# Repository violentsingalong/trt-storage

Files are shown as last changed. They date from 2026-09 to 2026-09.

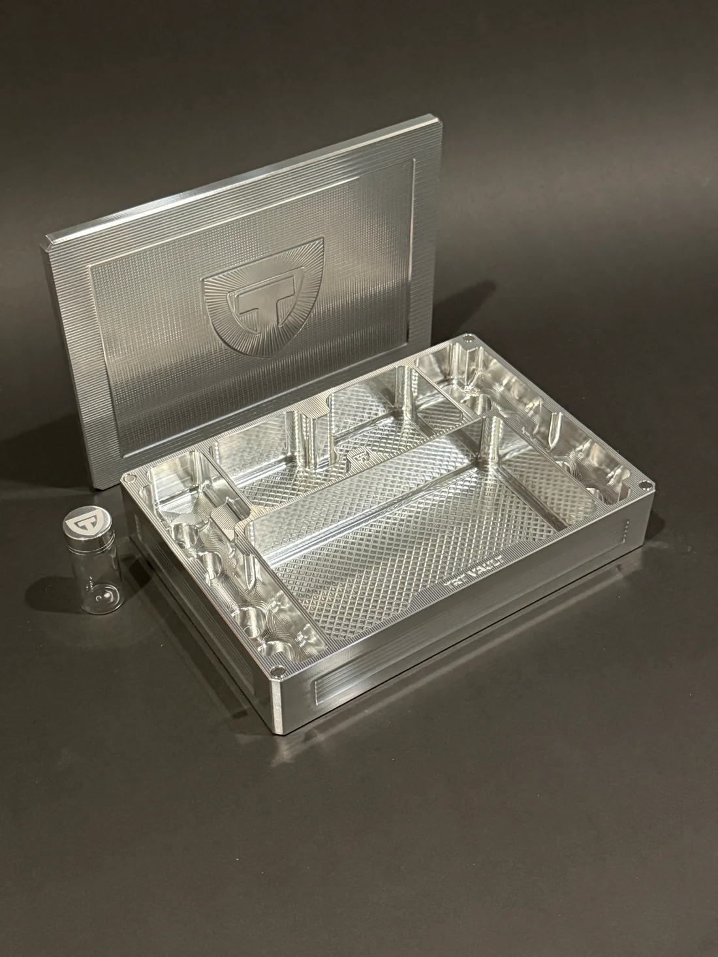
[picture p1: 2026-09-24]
reference/mega_reference.png

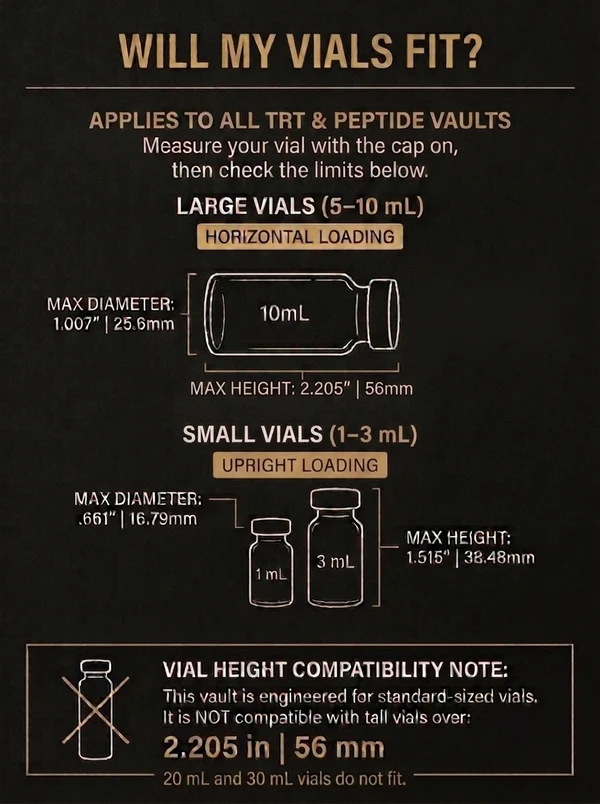
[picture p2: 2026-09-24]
reference/vial_fit_infographic.png

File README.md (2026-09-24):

# Vault Lite

Vault Lite is a parametric, FDM-printable family of magnetic storage cases for medication vials, injection supplies, and related accessories. It is designed for PETG on a Bambu Lab X1 Carbon and uses shared interfaces so matching footprints can stack as modular storage layers.

Commercial products are used only as functional and dimensional references. Vault Lite uses original CAD, visual treatment, and branding.

## Project status

**Current stage: V0.1 calibration complete; stack-interface and Mini prototype are next.**

| Item | Result |
|---|---|
| Small-vial cavity | 17.00 mm tested with current 3 mL vial |
| Horizontal large-vial trough | 26.00 mm selected across several current vials |
| Magnets | Round 6 × 2 mm |
| Magnet pocket | 6.20 mm diameter × 2.20 mm deep; insertion tested |
| Magnet cover | 0.80 mm selected for best surface finish; mating hold test pending |
| CAD toolchain | Dockerized OpenSCAD + ADMesh |
| Printable artifacts | Horizontal vial-fit, vertical vial-well, and magnet-cover coupon STLs exported and validated |

See [the dimension register](docs/dimensions.md) for the distinction between known, inferred, and physically tested values. Packaging envelopes and measurement requirements for prep pads, syringes, and sterile needles are tracked in [the supply-dimensions study](docs/supply-dimensions.md).

## Planned models

### Mini

- Exterior: **152.4 × 127.0 × 44.45 mm**
- Six upright 1–3 mL vial positions
- Secondary supply compartments
- Removable magnetic lid

### Mega

- Exterior: **220 × 160 × 44.45 mm**
- Horizontal 5–10 mL vial storage
- Selectable TRT/supply, expanded vial, and open-cavity layouts

### Cycle Mega

- Exterior: **220 × 160 × 63.5 mm**
- Fourteen upright 5–10 mL vial positions
- Taller variant sharing the Mega X/Y footprint and stack datum
- No fitted 1–3 mL storage

### Future Micro

- Reference footprint: **152.4 × 76.2 mm**
- Recorded for future interface compatibility; not currently part of V1 scope

The 220 × 160 mm footprint is the original Vault Lite Large standard rather than a dimensional copy of the commercial reference. All listed bodies and lids fit within the X1C's 256 × 256 mm build area.

## Modular stack system

Every body is also a storage layer:

- same-footprint layers can stack in any order;
- purpose-built and open-cavity layers share one interface;
- intermediate layers may be lidless;
- only the uppermost layer requires a lid;
- printed registration geometry carries lateral loads;
- corner magnets provide retention rather than alignment;
- lids, parked lids, and stacked bodies use one documented polarity convention.

The registration geometry and polarity map remain under development and will be selected using a two-plate physical coupon.

## Lid appearance

The default lid is monochrome black with a centered, shallow raised user-supplied emblem and a slightly taller perimeter bezel. The bezel protects the emblem and becomes the structural bearing surface when modules stack. The emblem remains a separate CAD region for an optional two-color AMS version.

See [the lid visual-language specification](docs/lid-visual-language.md).

## Repository layout

```text
cad/             Parametric OpenSCAD sources and shared parameters
docs/            Specifications, tested dimensions, and print instructions
exports/stl/     Generated printable meshes
exports/3mf/     Bambu Studio projects after slicer validation
prototypes/      Prototype notes and future iteration artifacts
reference/       Functional and dimensional reference images
```

## Generate and validate models

Requirements: Docker with the Compose plugin.

```sh
make image          # build the local OpenSCAD/ADMesh image
make check          # generate and validate the vial coupon
make check-magnet   # generate and validate the magnet coupon
make check-vertical # generate and validate the Cycle Mega vertical-well coupon
make check-liners    # generate and validate removable vial-liner iterations
make check-liners-v2 # generate and validate the full-depth G1/G3/K1 pass
make check-liner-g3-v3 # generate and validate the single relieved G3 revision
make check-fuzzy     # generate and validate three minimal fuzzy-skin cards
make check-cycle-tray-v0 # generate and validate the shallow Cycle layout study
make check-all      # generate and validate all calibration coupons
```

Generated files are written to `exports/stl/` as the invoking host user.

## Calibration artifacts

### Vial-fit coupon

[Download the current STL](exports/stl/vault-lite-v0.1-vial-coupon.stl)

- Upright wells: 17.0, 17.2, 17.4, and 17.6 mm
- Full-length horizontal troughs: 25.8–26.6 mm
- Current selections: 17.0 mm small-vial cavity and 26.0 mm large-vial trough

### Magnet-cover coupon

[Download the current STL](exports/stl/vault-lite-v0.1-magnet-cover-coupon.stl)

- Magnet: 6 × 2 mm round disc
- Pocket: 6.20 × 2.20 mm
- Tested covers: 0.4, 0.6, and 0.8 mm
- Current selection: 0.8 mm, pending mating-force validation

Follow the [Bambu Studio pause procedure](docs/bambu-studio-magnet-coupon.md). Inserted magnets are encapsulated permanently by this coupon.

### Vertical large-vial coupon

[Download the current STL](exports/stl/vault-lite-v0.1-vertical-vial-coupon.stl)

- Upright wells: 25.4, 25.6, and 25.8 mm
- Well depth: 24 mm with a 1 mm entry chamfer
- Intended to select the Cycle Mega upright-well diameter using the measured vial assortment

### Removable vial-liner iterations

[Download the current STL](exports/stl/vault-lite-v0.1-vial-liner-iterations.stl)

- Three Gereropharm split collars: 24.0, 24.2, and 24.4 mm IDs
- Three KOSA split collars: 22.4, 22.6, and 22.8 mm IDs
- Common provisional outer diameter: 25.4 mm for the selected 25.6 mm well
- Integrated pull tabs and engraved G1–G3/K1–K3 identifiers

### Full-depth vial-liner V2 pass

[Download the current V2 STL](exports/stl/vault-lite-v0.2-vial-liners-g1-g3-k1.stl)

- G1: 24.0 mm ID for Gereropharm
- G3: 24.4 mm ID for Gereropharm
- K1: 22.4 mm ID for KOSA
- Common 25.1 mm OD for 0.5 mm nominal diametral clearance in the 25.6 mm well
- Full 24 mm well depth with the extraction ear above the rim
- Larger labels plus physical notch coding; omitted G2/K2/K3 to minimize material

### Gereropharm G3 printable-wall revision

[Download the current G3 STL](exports/stl/vault-lite-v0.3-vial-liner-g3.stl)

- Single 24.4 mm ID Gereropharm liner
- 25.3 mm outer envelope creates a 0.45 mm radial wall for the 0.4 mm nozzle profile
- Two vertical relief slots and the primary split create flexible petals above a 2 mm connecting band
- Full 24 mm depth with above-rim extraction ear

This STL is retained as an archived test artifact. Physical evaluation established that the measured Gereropharm vial fits the standard 25.6 mm well adequately without a liner. K1 remains the only active liner candidate.

### Cycle tray V0 layout study

[Download the shallow layout-study STL](exports/stl/vault-lite-v0.1-cycle-tray-layout-study.stl)

- Fourteen tested-diameter 25.6 mm upright wells
- Mirrored five-plus-two well banks
- One continuous raised deck with overlapping 34 mm spherical divots and no drop gaps
- Supply cavities share the exterior tray wall instead of duplicating it
- Reserved 8 mm top/bottom walls plus side structure for the planned six-position bar-magnet interface
- Approximately 84.0 × 57.6 mm usable upper packet bay
- Approximately 142.0 × 84.0 mm usable lower packaged-supply bay
- Shallow 26.4 mm review artifact; not yet the final magnetic 63.5 mm body

See [the Cycle tray V0 design note](docs/cycle-tray-v0.md).

## Prototype printing assumptions

- Material: PETG
- Printer: Bambu Lab X1 Carbon
- Body orientation: cavity upward
- Initial production profile: 0.20 mm layer height and four walls
- Exterior finish: normal smooth PETG; fuzzy skin was tested and rejected because it introduced additional artifacts
- Calibration-only vial coupon: 0.24 mm Draft, three walls, 15% gyroid is acceptable
- Supports should be avoided through geometry wherever practical

Final settings will be published only after the body and lid are physically validated.

## Roadmap and issues

Outstanding work is tracked in [GitHub Issues](https://github.com/violentsingalong/trt-storage/issues). The implementation order is:

1. Validate the shared magnetic stack and alignment interface.
2. Build and physically iterate the Mini body and lid.
3. Build and physically iterate the standard Mega layouts.
4. Build the taller Cycle Mega variant.
5. Add matching open-cavity modular layers.
6. Finalize lid artwork, Bambu Studio projects, and release documentation.

The detailed engineering sequence remains in [the project plan](docs/project-plan.md).

## Design constraints

- Keep all geometry parametric and source-controlled.
- Label photograph-derived measurements as inferred.
- Do not reproduce third-party logos, names, or decorative engraving.
- Ensure inserted magnets sit below the active print plane before resuming a paused print.
- Use mechanical indexing so magnets do not carry all lateral shear.
- Validate real storage objects before calling a model production-ready.

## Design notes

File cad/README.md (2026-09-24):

# CAD sources

- `parameters.scad` — single source for shared dimensions and uncertainty status.
- `primitives.scad` — reusable printable geometry.
- `calibration_coupon.scad` — vial-clearance artifact with four upright small-vial wells and five full-length large-vial troughs.
- `magnet_coupon.scad` — three-cover encapsulation test for the measured 6 × 2 mm disc magnets.
- `vertical_vial_coupon.scad` — deep-wall upright-vial fit test for the Cycle Mega family.
- `vial_liner_coupon.scad` — six removable split-collar iterations for narrower large vials.
- `vial_liner_coupon_v2.scad` — full-depth G1/G3/K1 pass with increased well clearance and robust identifiers.
- `vial_liner_g3_v3.scad` — single printable-wall G3 revision with flexible relief slots.
- `fuzzy_skin_coupon.scad` — minimal upright wall card rendered in three labeled variants for per-object Bambu Studio texture settings.
- `cycle_tray_v0.scad` — shallow 14-vial Cycle layout study with upper packet and lower packaged-supply bays; magnet/stack geometry intentionally deferred.

The recommended reproducible workflow uses the included Docker container:

```sh
make image
make check
```

`make check` renders `exports/stl/vault-lite-v0.1-vial-coupon.stl` and then checks the mesh with ADMesh. Files are written as the invoking host user rather than root.

`make check-magnet` renders and checks the 6 × 2 mm magnet-cover coupon. With a 0.20 mm layer height, inspect the slicer preview and pause immediately before the first sealing layer above the nominal 4.60 mm pocket roof. Insert all three magnets with identical polarity and ensure they sit below the active print plane before resuming.

`make check-vertical` renders and checks the 25.4–25.8 mm vertical 5–10 mL vial-well coupon.

`make check-liners` renders and checks the Gereropharm and KOSA split-collar iteration set.

`make check-liners-v2` renders and checks only the full-depth G1, G3, and K1 V2 liners selected after the first physical test.

`make check-liner-g3-v3` renders and checks the single 24.4 mm ID G3 revision after the V2 wall was omitted by the 0.4 mm nozzle slicer profile.

`make check-fuzzy` renders and checks the three 0.05/0.08/0.12 fuzzy-skin cards. The STLs contain labels but no texture; assign the per-object slicer settings in `../docs/bambu-studio-fuzzy-coupon.md`.

`make check-cycle-tray-v0` renders and checks the shallow Cycle tray layout study. This is a plan and ergonomics artifact, not the final 63.5 mm magnetic body.

See `../docs/bambu-studio-magnet-coupon.md` for the Bambu Studio procedure. Save the sliced setup with its verified pause as a Bambu `.3mf` project rather than relying on a fixed layer number in the raw STL.

If OpenSCAD is installed directly on the host, the equivalent export from this directory is:

```sh
openscad -o ../exports/stl/vault-lite-v0.1-vial-coupon.stl calibration_coupon.scad
```

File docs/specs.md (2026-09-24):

# Engineering Specification

## 1. Hard constraints / known inputs

### Printer
Bambu Lab X1 Carbon build envelope: **256 × 256 × 256 mm**

### Mini envelope
- X: 152.40 mm
- Y: 127.00 mm
- Z: 44.45 mm

### Vault Lite Large envelope
- X: 220.00 mm
- Y: 160.00 mm
- Z: 44.45 mm

The commercial Mega reference is 215.90 × 152.40 mm, but Vault Lite is not constrained to that footprint. The selected 220 × 160 mm metric footprint provides safe bar-magnet landing zones and is shared by standard Large, Cycle, and open-layer variants.

### Reference ecosystem Micro envelope
- X: 152.40 mm
- Y: 76.20 mm
- Z: 44.45 mm
- recorded for future interface compatibility; not a V1 deliverable yet

### Vial compatibility
Large vials (5–10 mL), horizontal:
- max diameter: **25.60 mm**
- max overall length: **56.00 mm**

Small vials (1–3 mL), upright:
- max diameter: **16.79 mm**
- max height: **38.48 mm**

These are vial envelopes, not cavity dimensions.

## 2. Reference observations

### Mini
The supplied top view shows:
- four corner magnets;
- thin perimeter rail;
- three principal storage zones;
- upper-left 3 × 2 small-vial pattern;
- upper-right general-purpose compartment with finger-access reliefs;
- large lower supply compartment with central finger relief;
- shallow textured floors.

The vial geometry appears to support overlapping horizontal large-vial use. Exact interior dimensions are unknown and photo-derived estimates must be tagged `INFERRED`.

### Mega
The supplied oblique image shows:
- four corner magnets;
- same general magnetic-lid language;
- multiple long supply channels/compartments;
- repeated vial-access scallops along one side;
- large central/lower storage area;
- monolithic machined body.

The added near-top-down loaded view also shows:
- mirrored left/right horizontal-vial banks;
- two upper alcohol-swab bays;
- one broad lower syringe/supply bay;
- finger-access notches at the central bays.

### Mega main-box layout options

Keep the Mega source capable of generating more than one interior layout while preserving the same exterior, lid, magnet, and stacking interface:

1. **TRT + supplies:** mirrored horizontal large-vial banks, upper swab compartments, and a broad syringe/supply bay.
2. **Vials + pill containers:** increase the count of universal horizontal large-vial channels; each channel retains the 25.60 × 56.00 mm compatibility envelope and therefore also accepts the user's candidate pill containers at approximately 21.0 × 51.5 mm.
3. **Open main box:** one large cavity for unconstrained storage, using the same modular-layer interface.
4. **Cycle Large family (separate height variant):** mirrored upright 5–10 mL vial banks along the left and right edges, one centered upper swab/packet bay with bilateral finger access, and one large centered lower syringe/supply bay. This is not a 44.45 mm Large interior option; it requires a taller body while retaining the 220 × 160 mm X/Y footprint and stack-interface datum.

The pill container is a fit-use case, not a controlling design dimension. Do not narrow universal channels around that specific product.

The Cycle Mega is deliberately for upright 5–10 mL vials and does **not** provide fitted 1–3 mL positions; small vials would sit loose and may rattle. Preserve adequate finger access between adjacent large-vial positions and at the swab bay.

Use **25.60 mm** as the uniform Cycle Mega upright-well diameter. The 25.40 mm coupon well fit the 25.04 mm Pharmacom vial closely, but 25.60 mm was selected to tolerate label seams, glass variation, and other minor imperfections without compromising insertion.

Support the narrower KOSA vial with an optional removable reducer liner rather than multiple permanent well sizes. The measured Gereropharm vial is accepted directly in the 25.60 mm well without a liner. Preferred remaining liner concept:

- full-well-depth split collar or compliant insert;
- smooth PETG contact surfaces, with TPU retained as an optional high-grip variant;
- common outer geometry fitting the 25.60 mm well;
- K1/22.40 mm candidate inner geometry for the measured KOSA vial;
- three shallow internal centering ribs where practical to reduce material and label drag;
- positive finger-removal feature entirely above the rim so the insert bottoms before the feature carries insertion load;
- enough compliance to accommodate label seams and vial ovality;
- no insert required for the Pharmacom or Gereropharm vial.

Validate liner outer clearance, retention, vial release, and whether the insert lifts out with the vial using a dedicated small coupon before integrating it into the Cycle Mega release.

Use **63.50 mm (2.5 inches)** as the Cycle Mega reference exterior height, based on the written product specification. An image on the same page lists 2.25 inches; treat that graphic as inconsistent or outdated rather than allowing it to override the page's explicit Dimensions & Build section. The printable design must still verify that its floor, lid, and safe Z clearances fit the 56 mm capped-vial envelope.

Perspective correction may estimate proportions, but resulting measurements remain `INFERRED`.

## 3. Minimum parameter set

```text
mini_x = 152.40
mini_y = 127.00
mega_x = 220.00
mega_y = 160.00
case_z = 44.45

small_vial_max_d = 16.79
small_vial_max_h = 38.48
large_vial_max_d = 25.60
large_vial_max_l = 56.00

small_vial_clearance = TBD_FROM_COUPON
large_vial_clearance = TBD_FROM_COUPON

magnet_x_or_d = REQUIRED_USER_INPUT
magnet_y = REQUIRED_USER_INPUT_IF_RECTANGULAR
magnet_z = REQUIRED_USER_INPUT
magnet_cover = TBD_FROM_COUPON

lid_gap_xy = PARAMETRIC
alignment_clearance = PARAMETRIC
outer_corner_radius = PARAMETRIC
min_wall = PARAMETRIC
floor_thickness = PARAMETRIC
lid_thickness = PARAMETRIC
```

Measured magnet input: round disc, **6.00 mm diameter × 2.00 mm thick**. The first coupon uses a 6.20 mm diameter × 2.20 mm deep pocket, which accepted all three test magnets. Of the tested 0.4, 0.6, and 0.8 mm covers, **0.8 mm produced the best visual surface with only slight magnet witness**. Treat 0.8 mm as preferred pending body-to-lid holding-force testing.

Never silently invent magnet dimensions.

## 4. FDM adaptation rules

The reference is CNC aluminum and cannot simply be copied dimension-for-dimension.

Starting guidelines:
- structural dividers: ~2.0–2.5 mm minimum unless testing supports thinner;
- printable fillets/chamfers;
- avoid deep unsupported horizontal ceilings;
- magnet encapsulation roof must bridge reliably;
- clearance around real vials rather than nominal zero-clearance fits;
- finger reliefs for tightly packed supplies.

## 5. Lid

Desired:
- removable slab-style lid;
- four-corner magnetic retention;
- tongue/rebate, bosses, or equivalent geometry controlling X/Y movement;
- easy finger access;
- visually flush/near-flush perimeter;
- optional magnetic parking beneath body.

Do not rely on magnets alone for lateral registration.

## 5A. Stack interface

Every case body is also a modular storage layer. The interface must support:
- stacking only with an identical X/Y footprint;
- a lidded top layer or a lidless intermediate layer;
- repeatable X/Y registration using printable mechanical geometry;
- four-corner magnetic retention using one documented polarity map;
- body-to-body stacking and lid parking without polarity conflicts;
- separation by hand without tools or excessive prying force;
- a flat, printable body underside without support-heavy recesses.

Interface geometry is `TBD_FROM_COUPON`. Do not finalize corner offsets, magnet pockets, registration depth, or polarity until actual magnets are measured and a two-plate stack coupon is tested.

Open-cavity layers should target the published reference cavity depth of approximately 34.0 mm only after floor, interface, and lid geometry are reconciled within the 44.45 mm exterior height.

## 6. Pause-and-insert magnet process

1. Print until magnet pocket is open.
2. Pause before sealing layers.
3. Insert magnets using a polarity map/jig.
4. Confirm magnets are below the current print plane.
5. Resume and bridge/seal pockets.

## 7. Calibration coupon

### Small vial wells
17.0 / 17.2 / 17.4 / 17.6 mm IDs.

### Large vial troughs
25.8 / 26.0 / 26.2 / 26.4 / 26.6 mm effective diameters.

Each trough must provide at least 60 mm of usable axial length so the known 56 mm maximum large vial can be seated completely rather than testing diameter at only one short contact section.

Physical coupon result: use **26.00 mm effective diameter** for the current horizontal large-vial configuration. Multiple differently sized user vials fit comfortably, and the semicircular exposure provides useful finger access. This selection is tested for the user's assortment and supplies 0.40 mm nominal diametral clearance over the published 25.60 mm envelope.

### Magnet covers
After magnet dimensions are known: 0.4 / 0.6 / 0.8 mm.

Record insertion feel, rattle, grip strength, removal effort, and print artifacts.

## 8. Open measurements

Required before final magnet design:
- magnet shape;
- diameter OR length × width;
- thickness;
- quantity available.

Useful validation:
- actual 10 mL vial dimensions;
- actual peptide vial dimensions;
- syringe dimensions;
- alcohol-swab packet dimensions;
- pill vial/accessory dimensions.

The manufacturer maximum vial envelopes remain compatibility targets even if current supplies are smaller.

## 9. Originality

Use commercial references for functional inspiration and dimensional interoperability. Do not reproduce the TRT Vault name, shield/T logo, decorative engraving, or branding. Develop original surface treatment and labeling.

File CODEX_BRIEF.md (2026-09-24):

# Codex Project Brief

Implement a parametric FDM storage-case project called **Vault Lite**.

Read:
1. `README.md`
2. `docs/specs.md`
3. `docs/project-plan.md`
4. all files in `reference/`

Rules:
- Separate KNOWN, INFERRED, and TESTED dimensions.
- Never invent unknown magnet dimensions.
- Keep geometry parametric and source-controlled.
- Prefer OpenSCAD initially unless another scriptable CAD workflow clearly improves the result.
- Design for PETG on a Bambu Lab X1 Carbon.
- First printable artifact is a calibration coupon, not a full case.
- Do not copy third-party logos or branding.
- Commercial products are functional/layout references, not a request for a trademark-identical replica.
- Mini and Mega should share reusable CAD primitives and visual language.
- Document uncertainty for every photo-derived measurement.

Start by:
1. creating the CAD skeleton and central parameter file;
2. documenting KNOWN / INFERRED / TBD dimensions;
3. analyzing the Mini reference;
4. producing a first calibration-coupon source file that can be completed once magnet dimensions are supplied.

Do not proceed to a production-ready case while required physical dimensions remain unresolved.

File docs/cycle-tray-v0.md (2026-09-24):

# Cycle tray V0 layout study

This shallow study establishes the interior plan before the ordered bar magnets and shared stack interface are physically validated. It is not the final 63.5 mm body.

## Plan

- Footprint: **220 × 160 mm**, the selected Vault Lite Large standard. The former 215.9 × 152.4 mm footprint remains a commercial reference only.
- Fourteen 25.6 mm upright vial wells cut into one continuous monolithic deck.
- Left and right banks each contain five wells in the outer column plus two wells at the packet end of the inner column.
- Retaining-well height: 24 mm above a 2.4 mm floor.
- Each opening has a 34 mm shallow spherical divot. Adjacent divots overlap intentionally to create a continuous machined appearance and improve vial access.
- The closed deck prevents small supplies and debris from falling between vial cylinders, supply bins, and the outer wall; the slicer may use normal internal infill rather than printing the deck solid.
- The upper and lower supply cavities use the exterior tray wall directly at the top and bottom edges. There is no redundant parallel compartment wall.
- The two supply cavities share one 2.4 mm internal divider.
- Reserved top and bottom long-edge magnet walls: 8.0 mm wide, reclaimed from the wipe and syringe cavities; exact pockets remain pending physical tests.
- Upper packet-bay usable opening: approximately 84.0 × 57.6 mm.
- Lower packaged-supply-bay usable opening: approximately 142.0 × 84.0 mm.
- Upper bay has bilateral finger-access scallops.
- The measured 136 mm sterile 1 mL syringe package fits lengthwise in the lower bay with approximately 6.0 mm total nominal allowance.
- The common approximately 50 × 50 mm alcohol-prep packet envelope fits the upper bay.

## Deferred geometry

- 20 × 5 × 2 mm bar-magnet pockets and polarity map;
- exposed versus 0.8 mm-covered magnetic faces;
- final lid seat and stack registration;
- final full-height perimeter and exact 56 mm lid clearance;
- corner landing pads shared by lid and body-to-body stacking.

The source can preview a provisional full-height perimeter using `LAYOUT_STUDY=false`, but that mode is intentionally not treated as a production body until the magnetic interface is selected.

The first and last vial rows leave 9.2 mm between the 25.6 mm vial envelope and the top/bottom exterior edges. This provides 1.2 mm of nominal PETG between the vial envelope and each reserved 8 mm long-edge wall. The outer vial columns were also shifted inward to reserve separate left/right magnet structure. Together these zones can support a six-position layout—two pockets per short edge and one centered pocket per long edge—without expanding the footprint; exact pockets remain pending physical magnet tests.

## Review before a full body print

- Confirm the five-plus-two well pattern matches the intended Cycle layout.
- Review the overlapping 34 mm spherical divots and confirm the depth/visual rhythm before a full-height print.
- Confirm a single upper packet bay is preferred over a divider.
- Place representative packaged syringes/needles on the plan or in a shallow print and assess retrieval.
- Confirm the lower bay should remain one bulk bin rather than receive a removable divider.

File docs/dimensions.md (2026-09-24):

# Dimension register

All dimensions are millimetres. `INFERRED` values must not be treated as production measurements, and `TESTED` values must name the print/material used.

| Feature | Value | Status | Source / note |
|---|---:|---|---|
| Micro exterior X × Y × Z | 152.40 × 76.20 × 44.45 | KNOWN_REFERENCE | Published 6 × 3 × 1.75 in footprint; future scope |
| Mini exterior X × Y × Z | 152.40 × 127.00 × 44.45 | KNOWN | Supplied handoff |
| Commercial Mega reference X × Y × Z | 215.90 × 152.40 × 44.45 | KNOWN_REFERENCE | Functional reference only; no longer the controlling printable footprint |
| Vault Lite Large exterior X × Y × Z | 220.00 × 160.00 × 44.45 | SELECTED_DESIGN | Shared metric footprint for Large, Cycle, and open-layer modules |
| Small vial maximum Ø × H | 16.79 × 38.48 | KNOWN | Supplied compatibility graphic |
| Large vial maximum Ø × L | 25.60 × 56.00 | KNOWN | Supplied compatibility graphic |
| User's tallest current large vial, cap included | 55.00 long | KNOWN_USER_MEASURED | Physical vial measurement supplied by user |
| Gereropharm vial: body Ø / cap Ø / overall H / straight body H | 23.87 / 22.20 / 54.40 / 40.50 | KNOWN_USER_MEASURED | Body diameter includes label |
| Pharmacom vial: body Ø / cap Ø / overall H / straight body H | 25.04 / 21.76 / 44.89 / 31.90 | KNOWN_USER_MEASURED | Body diameter includes label; preferred brand and largest measured body |
| KOSA vial: body Ø / cap Ø / overall H / straight body H | 22.21 / 22.04 / 54.01 / 42.05 | KNOWN_USER_MEASURED | Body diameter includes label |
| Candidate pill container Ø × capped length | ≈21.0 × 51.5 | REFERENCE_ONLY | Product listing; fits universal large-vial channel but does not control geometry |
| Small-vial pocket pattern | 3 × 2 | INFERRED | Mini reference photograph |
| Corner magnet count | 4 per mating part | INFERRED | Mini and Mega photographs |
| Mega major storage arrangement | 2 side vial banks + 2 upper bays + 1 lower bay | INFERRED | Near-top-down loaded Mega photograph |
| Cycle Mega arrangement | 14 upright 5–10 mL positions + upper packet bay + lower supply bay | KNOWN_REFERENCE | Separate taller variant; excludes fitted 1–3 mL storage |
| Commercial Cycle Mega reference X × Y × Z | 215.90 × 152.40 × 63.50 | KNOWN_REFERENCE | Written product specification: 8.5 × 6 × 2.5 in; same-page comparison graphic inconsistently says 2.25 in |
| Vault Lite Cycle exterior X × Y × Z | 220.00 × 160.00 × 63.50 | SELECTED_DESIGN | Uses the shared Vault Lite Large footprint; height remains provisional pending lid/interface reconciliation |
| Vault Lite Large top/bottom magnet walls | 8.00 wide | PROVISIONAL_LAYOUT | Highlighted long-edge walls; reclaimed from wipe/syringe cavity depth for 20 × 5 mm bar-pocket study |
| Cycle Mega provisional clear internal height | 56.00 | PROVISIONAL | Controlled by 54.40 mm tallest measured standing vial; provides 1.60 mm nominal top clearance |
| Magnet shape and size | round Ø6.00 × 2.00 | KNOWN_USER_MEASURED | User-supplied magnet dimensions |
| Magnet pocket Ø × depth | 6.20 × 2.20 | TESTED_INSERTION | All three 6 × 2 mm magnets seated successfully in coupon; retention/production repeatability pending |
| Magnet encapsulation cover | 0.80 | TESTED_VISUAL | Least magnet witness/print-through of 0.4, 0.6, 0.8 mm coupon; holding force still pending |
| Small-vial cavity / clearance | 17.00 / 0.21 diametral | TESTED_CURRENT_VIAL | User reports comfortable fit with current 3 mL vial; nominal 16.79 mm maximum not physically tested |
| Large-vial trough / clearance | 26.00 / 0.40 diametral | TESTED_CURRENT_VIALS | User tested several differently sized capped vials; 26.0 mm reported as the sweet spot |
| Vertical large-vial well | 25.60 | TESTED_CURRENT_VIALS | Selected over snug 25.4 mm to tolerate vial imperfections and preserve smooth insertion |
| Reducer-liner V1 outer Ø / clearance | 25.40 / 0.20 diametral | TESTED_TOO_TIGHT | Gereropharm collars fit vial outside well but required excessive force in 25.60 mm well |
| Reducer-liner V2 candidate outer Ø / clearance | 25.10 / 0.50 diametral | PROVISIONAL_NEXT_COUPON | Increase reliable insertion clearance while retaining centering |
| Gereropharm liner G1, 24.0 ID | 0.13 nominal vial clearance | TESTED_TOO_TIGHT_IN_WELL | Assembly can be inserted together, but vial cannot be reinserted after removal |
| Gereropharm liner G3, 24.4 ID | 0.53 nominal vial clearance | SLICER_REJECTED_V2_WALL | 25.10 OD left 0.35 mm radial wall; 0.4 mm nozzle profile omitted collar toolpaths |
| Gereropharm in 25.6 well | 1.73 diametral / 0.865 radial clearance | ACCEPTED_NO_LINER | User accepts direct fit; dedicated Gereropharm liner development closed as unnecessary |
| Gereropharm liner G3 V3, 24.4 ID / 25.3 OD | 0.45 radial wall / 0.30 well clearance | ARCHIVED_TEST_ARTIFACT | Superseded by accepted direct vial fit; retained only as development history |
| KOSA liner IDs | 22.4 / 22.6 / 22.8 | PARTIAL_TEST | Suspected K1/22.4 fit 22.21 mm vial; poor label legibility prevents definitive identification |
| Reducer-liner V2 height | 24.00 | PROVISIONAL_NEXT_COUPON | Full test-well depth; extraction feature must sit entirely above rim |
| Common alcohol-prep pouch | ≈50 × 50 | REFERENCE_ONLY | Published examples; actual sealed packets and stack height still required |
| Provisional alcohol-prep bay usable X × Y | 54 × 55 | INFERRED | Intended for common 50 × 50 mm packets with finger relief |
| Provisional loose-syringe bay usable X × Y | 160 × 90 | INFERRED | Photo-derived Mega/Cycle study; final size depends on stored 1 mL and 3 mL assemblies |
| Sterile 1 mL syringe package length | 136.0 | KNOWN_USER_MEASURED | Longer than user's packaged 3 mL syringe; current syringe-package length controller |
| Individually wrapped 1-inch Luer-lock needle package length | ≈91.0 | KNOWN_USER_MEASURED | Shared bulk bin; individual package width does not control geometry |
| Lid XY clearance | 0.30 provisional | INFERRED | Must be calibrated with alignment test |
| Structural wall | 2.40 provisional | INFERRED | PETG starting rule, not yet tested |
| Exterior PETG surface finish | Normal smooth / fuzzy skin disabled | TESTED_SELECTION | 0.12 mm thickness at 0.40 mm distance was best fuzzy sample, but showed more artifacts than normal finish |
| Reference open-cavity depth | ≈34.0 | KNOWN_REFERENCE | Published 1.34 in; reconcile printable floor/interface |
| Stack registration geometry | — | TBD | Select using two-plate PETG coupon |
| Stack magnet polarity map | — | TBD | Requires actual magnets and physical polarity jig |

## Reference-analysis limits

The Mini image is close to top-down but still contains lens/perspective error and no scale object on the same plane. The exterior aspect ratio can constrain a later rectification, but internal dimensions remain estimates. The original Mega image is strongly oblique; the added loaded top view is better for layout interpretation, but supplies obscure compartment edges and it is still unsuitable for precise measurements. For the first prototype, storage-object measurements should control geometry rather than pixel-derived pocket sizes.

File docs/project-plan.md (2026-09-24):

# Project Plan

## Phase 0 — Repository bootstrap
- Create parametric CAD source structure.
- Centralize parameters.
- Preserve reference images.
- Maintain a KNOWN / INFERRED / TESTED dimension log.
- Establish reproducible export commands.
- Define one versioned lid/body/stack interface shared by all footprints.

**Exit:** repository can generate a simple STL reproducibly.

## Phase 1 — Reference analysis

### Mini
- Rectify near-top-down image using known 152.4 × 127.0 mm envelope.
- Estimate compartment boundaries, vial-center pitch, corner magnet positions, wall widths, radii, and finger reliefs.
- Cross-check scale against known vial envelope.

### Mega
- Perspective-correct the commercial reference using its known 215.9 × 152.4 mm envelope; do not treat that as the controlling Vault Lite footprint.
- Estimate major compartment boundaries and repeated geometry.
- Explicitly label confidence/uncertainty.

**Exit:** dimension sketches/tables with confidence labels.

## Phase 2 — Calibration coupon
- Generate vial-fit ladder.
- Add magnet-cover samples after magnet dimensions arrive.
- Add small alignment-lip test if useful.
- Add two mating stack plates to test registration clearance, separation feel, and magnet polarity.
- Export STL.
- User prints in PETG on X1C and reports fit.

**Exit:** tested vial clearances and magnet cover thickness.

## Phase 3 — Mini prototype
- Model Mini body and lid.
- Use calibrated vial clearances.
- Six upright small-vial positions.
- Preserve compact three-zone organization inspired by reference.
- Finger reliefs.
- Four corner magnet pockets.
- Stack-compatible underside using the shared interface.
- Document slicer pause layer.

Evaluate vial fit, lid registration, magnet force, usability, warping, and surface quality.

**Exit:** Mini issue list or accepted geometry.

## Phase 4 — Mini refinement
- Correct from physical feedback.
- Improve chamfers/radii/surface treatment.
- Add restrained original labeling only after geometry is stable.

**Exit:** Mini release candidate.

## Phase 5 — Mega prototype
- Reuse shared case/lid primitives.
- Target the selected 220 × 160 × 44.45 mm Vault Lite Large envelope.
- Prioritize horizontal 5–10 mL vial storage and larger supply storage.
- Make the 44.45 mm interior layout selectable: TRT/supplies, expanded universal vial-and-pill-container channels, or open main box.
- Treat Cycle Mega as a separate taller body sharing the Mega X/Y footprint and stack interface; it stores 5–10 mL vials upright and intentionally omits fitted 1–3 mL storage.
- Use uniform 25.60 mm upright wells and provide optional removable reducer liners for narrower 5–10 mL vial bodies.
- Use same magnetic/alignment system where practical.
- Preserve the same stack-interface version and polarity convention as Mini.
- Body and lid each remain single-piece X1C prints.

**Exit:** Mega V0 STL.

## Phase 6 — Mega physical iteration
Repeat physical review loop.

**Exit:** Mega release candidate.

## Phase 7 — V1 release
- Normalize visual language across both sizes.
- Finalize documentation.
- Add print/assembly guide.
- Include at least one lidless open-cavity storage layer per released footprint.
- Export STLs.
- Add 3MF only after Bambu Studio settings are validated.

## Priority order
1. Correct fit
2. Reliable printing
3. Safe/repeatable magnet insertion
4. Lid feel/registration
5. Storage ergonomics
6. Appearance
7. Decoration

Do not spend substantial effort reproducing CNC floor texture during early prototypes.

## Decisions already made
- Bambu Lab X1 Carbon.
- Ordinary PETG for prototypes.
- Mini primarily for peptide/small-vial storage.
- Mega primarily for TRT/supply storage.
- Monolithic bodies for V1.
- Magnetic removable lids are core.
- Pause-and-insert captive magnets preferred.
- Four corner magnets initially.
- Same-footprint bodies form modular stacks; only the top layer requires a lid.
- Original branding only.

## Questions Codex should surface instead of guessing
- Exact magnet dimensions.
- Preferred lid thickness after magnet geometry is known.
- Supply dimensions when they materially affect layout.
- Whether underside lid parking is worth added complexity after V0.

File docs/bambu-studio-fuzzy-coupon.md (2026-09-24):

# Bambu Studio: fuzzy-skin coupon

The three STL cards are geometrically identical except for their recessed foot labels. Fuzzy skin is generated by Bambu Studio and is not stored in an STL.

## Import and arrange

1. Import all three fuzzy-skin coupon STLs as separate objects.
2. Keep them upright as modeled, with several millimetres between cards.
3. Use the intended black PETG and the same wall speeds planned for the case.
4. If bed adhesion is questionable, add a small brim to all three objects rather than changing their geometry.

## Per-object settings

Use **0.40 mm point distance** for all three objects and assign the labeled fuzzy-skin thickness to each card:

| Card label | Fuzzy-skin thickness | Point distance |
|---:|---:|---:|
| 0.05 | 0.05 mm | 0.40 mm |
| 0.08 | 0.08 mm | 0.40 mm |
| 0.12 | 0.12 mm | 0.40 mm |

Apply fuzzy skin to the exterior contour. Confirm in Preview that each broad vertical face receives texture. The feet and labels are not evaluation surfaces.

## Evaluation

Compare the cards under both direct and grazing light for:

- layer-line masking;
- visual uniformity;
- tactile roughness and grip;
- tendency to collect lint;
- corner definition;
- preference at normal viewing distance.

Record the selected thickness together with filament, nozzle, layer height, wall speed, and Bambu Studio profile. Do not apply fuzzy skin to lid fits, stack registration, bezel bearing surfaces, magnet interfaces, or interior storage surfaces.

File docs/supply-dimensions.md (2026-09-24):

# Supply dimension envelopes

This document separates published product dimensions, photo-derived layout estimates, and measurements still required from the user's actual supplies. All dimensions are millimetres.

## Alcohol prep pads

The controlling dimension for storage is the sealed foil pouch, not the unfolded wipe.

Published examples show a common pouch size of approximately **50 × 50 mm**:

- Wuxi Medical lists 50 × 50 mm foil packaging for common 65 × 30 mm and 65 × 60 mm pads.
- Other manufacturers list 50 × 45 mm and 65 × 65 mm pouch variants.
- Pouch thickness varies with pad ply, fluid load, seal, and trapped air and should be measured as a compressed stack rather than inferred from one packet.

Reference links:

- https://wuxi-medical.com/alcohol-swabs-manufacturer/
- https://chinamedica.com/product/alcohol-prep-pad/
- https://pdi-intl.com/products/prevantics-alcohol-prep-pad/

### Provisional compartment envelope

For common 50 × 50 mm packets, start with **54 × 55 mm usable X/Y** per bay, plus finger relief. This is consistent with the two upper packet stacks visible in the scaled Mega reference photograph, but remains `INFERRED` until actual packets are measured.

- Standard Mega: two bays of roughly 30 packets each.
- Cycle Mega: one deeper central bay may hold roughly 60 packets.
- Do not estimate capacity from single-packet thickness. Measure a lightly compressed stack of 10 and divide by 10, then validate a full intended stack.

## Syringes

Syringe dimensions vary substantially with barrel design, plunger position, tip style, attached needle, needle length, and protective cap. Volume alone is not enough to define a compartment.

The original loaded Mega reference shows loose capped syringe/needle assemblies rather than unopened sterile retail pouches. Photo rectification against the known 215.9 × 152.4 mm exterior suggests a lower usable bay of approximately **155 × 88 mm**, with several assemblies nested diagonally or longitudinally. Treat this as an `INFERRED` layout estimate with approximately ±3 mm uncertainty.

Official capacity claims provide quantity, not object dimensions:

- TRT Vault Mega: 12–20 syringes depending on syringe size.
- Cycle Vault Mega: 20–40 syringes depending on syringe size.

Reference links:

- https://www.trtvault.com/products/trt-vault-mega-anodized-black-1
- https://www.trtvault.com/products/cycle-vault-mega-anodized-black

### Provisional compartment envelope

Use **160 × 90 mm usable X/Y** as the first parametric syringe-bay envelope for Mega/Cycle studies. This is not yet a production dimension. The final bay must be driven by the longest stored 1 mL and 3 mL assemblies and the desired quantity.

The user's sterile 1 mL syringe package measures **136 mm long** and is longer than the user's packaged 3 mL syringe. It is therefore the current length-controlling syringe package. A 160 mm usable bay provides 24 mm of total longitudinal allowance. These packages will be stored loose in a shared bulk bin rather than fitted lanes, so individual package width does not control the geometry; capacity, compartment depth, and removal access remain to be validated.

## Individually wrapped 1-inch Luer-lock needles

Needles should be stored in their original sealed wrappers. The controlling object is therefore the **sterile package**, not the bare 1-inch needle or its protective cap. Catalogs confirm that sterile, single-use 1-inch Luer-compatible needles are commonly available in multiple gauges, but the reviewed manufacturer pages do not publish individual wrapper dimensions.

Reference links:

- https://www.bd.com/en-us/products-and-solutions/products/product-page.305127
- https://static.bd.com/assets/product/Documents/Medication%20Delivery%20Solutions%20(MDS)/Needles%20and%20Syringes/BD-14837%20(04-23)%20Needles%20and%20Syringes%20Cat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

### Compartment requirements

- Keep wrappers flat or gently stacked; do not force tight bends into the sealed edges.
- Provide finger access so a package can be lifted without scraping or pinching its sterile barrier.
- Use radiused divider edges and avoid a tight press fit.
- Use a shared bulk bin rather than fitted lanes for individual packages.
- Treat a shallow removable divider or dedicated flat bay as preferable to fitted slots for each needle.
- Do not assign a production envelope until an actual package and stack have been measured.

The user's current individually wrapped 1-inch Luer-lock needle package measures approximately **91 mm long**. Individual wrapper width does not control the loose-storage geometry. Desired quantity, resulting pile/stack height, usable compartment depth, and removal access will determine capacity.

## Measurements required from current supplies

Measure each 1 mL and 3 mL configuration exactly as it will be stored:

| Measurement | What to include |
|---|---|
| Overall stored length | Plunger position, attached needle, and protective cap |
| Maximum width | Finger flange or safety mechanism, whichever is wider |
| Maximum thickness | Barrel, flange, cap, or safety mechanism |
| Barrel diameter | Useful for nesting and divider geometry |
| Needle/cap length | Record separately if needles may be stored detached |
| Sterile pouch length | Only if supplies will remain packaged; width is non-controlling for the shared bulk bin |
| Quantity | Needed to validate bay width, depth, and stacking arrangement |

For individually wrapped 1-inch Luer-lock needles, measure:

- sealed wrapper length, including the seal flange;
- approximate pile/stack height at the desired quantity;
- all gauge/brand variants likely to be stored;
- desired stored quantity.

For alcohol pads, measure:

- sealed pouch X and Y;
- maximum seal-edge thickness if unusually stiff;
- compressed height of a stack of 10;
- desired stored quantity.

## Current layout assumptions

For the standing-vial Cycle Mega iteration, vial clearance controls the overall usable compartment height. The tallest currently measured vial is 54.4 mm, so use **56.0 mm provisional clear internal height** as the first layout target. Syringe, needle, and alcohol-pad bulk bins may use this available height but do not independently set the enclosure height.

| Feature | Provisional usable envelope | Status |
|---|---:|---|
| One common alcohol-pad bay | 54 × 55 | INFERRED / PENDING_USER_MEASUREMENT |
| Standard Mega combined alcohol-pad capacity | two bays, about 60 total | KNOWN_CAPACITY / INFERRED_LAYOUT |
| Mega/Cycle loose syringe bay | 160 × 90 | INFERRED / PENDING_USER_MEASUREMENT |
| Sterile 1 mL syringe package length | 136 | KNOWN_USER_MEASURED |
| Wrapped 1-inch Luer-lock needle length | ≈91 | KNOWN_USER_MEASURED |
| Wrapped 1-inch Luer-lock needle bulk bin | Length must accommodate ≈91 mm wrapper; width non-controlling | PENDING_CAPACITY_LAYOUT |
| Cycle Mega clear internal height | 56.0 | PROVISIONAL_FROM_TESTED_OBJECT |
| Standard Mega syringe capacity | 12–20 | KNOWN_REFERENCE |
| Cycle Mega syringe capacity | 20–40 | KNOWN_REFERENCE |

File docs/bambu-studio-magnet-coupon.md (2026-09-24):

# Bambu Studio: magnet-coupon pause

Model: `exports/stl/vault-lite-v0.1-magnet-cover-coupon.stl`

## Recommended setup

- Printer: Bambu Lab X1 Carbon
- Material: the PETG intended for the final case
- Layer height: 0.20 mm, with variable layer height disabled for this test
- Orientation: flat base on the build plate; labels and three square cells face upward
- Magnets: three round 6 × 2 mm discs

## Add the pause

1. Import the STL into Bambu Studio and confirm it remains 74 × 28 × 5.4 mm.
2. Select the intended X1C/PETG profile and slice the plate.
3. Open **Preview** and use the vertical layer slider on the right.
4. Inspect the layers around **Z = 4.60 mm**. The correct pause is immediately before the first layer that bridges across and seals the three circular magnet cavities.
5. On the layer slider, right-click the `+` marker at that boundary and choose **Add pause**.
6. Re-slice if Bambu Studio requests it, then return to Preview and verify the pause marker is still immediately before the sealing layer.
7. Save the complete project as a `.3mf`. The saved project is the reusable file that should retain the sliced setup and layer pause.

Do not rely only on a predicted layer number. Confirm the cavity is open below the pause and covered immediately above it. Changing layer height, variable-layer settings, model scale, orientation, or profile requires checking the pause again.

## At the printer

1. When the printer pauses, wait for the toolhead to park.
2. Insert one magnet into each cavity with all three magnets facing the same polarity direction.
3. Confirm every magnet is fully seated and below the current print plane. A proud magnet can strike the nozzle or toolhead.
4. Keep loose magnets away from the toolhead and build plate.
5. Resume the print from the printer or Bambu interface.

## After printing

Compare attraction through the covers labeled 0.4, 0.6, and 0.8. Record:

- whether the 6.20 mm pocket allowed easy insertion;
- whether magnets rattled or rose from the pockets;
- visible bridging or cover defects;
- relative magnetic holding force through each cover;
- the thinnest reliable cover you would trust in the final case.

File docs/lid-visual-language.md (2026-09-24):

# Lid visual language

## Emblem

Use the user-supplied three-arrow anchor-like symbol as the centered lid emblem. Preserve its recognizable outer silhouette and internal openings, but convert it to clean vector geometry before incorporating it into CAD; do not reproduce the raster texture or faux-metal shading.

Default treatment:

- print the lid and emblem in one black material;
- raise the emblem 0.60 mm above the lid field (three 0.20 mm layers);
- constrain the emblem to at most 42% of the lid's smaller dimension;
- center it geometrically on the visible lid field;
- soften or chamfer exposed top edges where the CAD workflow permits.

Keep the emblem as a separate CAD region even in the monochrome version. This preserves the option to assign it to another AMS filament in a Bambu Studio 3MF without rebuilding the lid.

## Protective perimeter bezel

Add a restrained raised bezel near the lid perimeter:

- 2.40 mm nominal width;
- 5.00 mm nominal inset from the exterior edge;
- 0.80 mm nominal height above the lid field;
- continuous except where an intentional finger-access or alignment feature requires interruption.

The bezel is 0.20 mm taller than the emblem. It should carry the compressive contact from a stacked module so the emblem is visually prominent but not used as the primary structural bearing surface.

## Stacking relationship

The underside of a mating body requires a relief at least 1.00 mm deep over the decorated lid field, plus the selected XY clearance. The perimeter registration feature should mate outside or directly above the bezel. Verify in section view that:

1. the upper body cannot contact the emblem;
2. lateral loads pass through registration geometry rather than the emblem;
3. the stack rests without rocking;
4. a lidless storage layer remains compatible with the same body underside;
5. the raised treatment does not interfere with lid parking beneath a body.

All values are provisional until a small bezel/relief stacking coupon is printed in PETG.

## AMS option

For a two-color version, keep the base lid and bezel black and assign only the emblem region to the accent filament. A 0.60 mm emblem limits color changes to the final three nominal layers. The monochrome black version remains the default because it avoids purge waste and emphasizes shape through light and shadow.

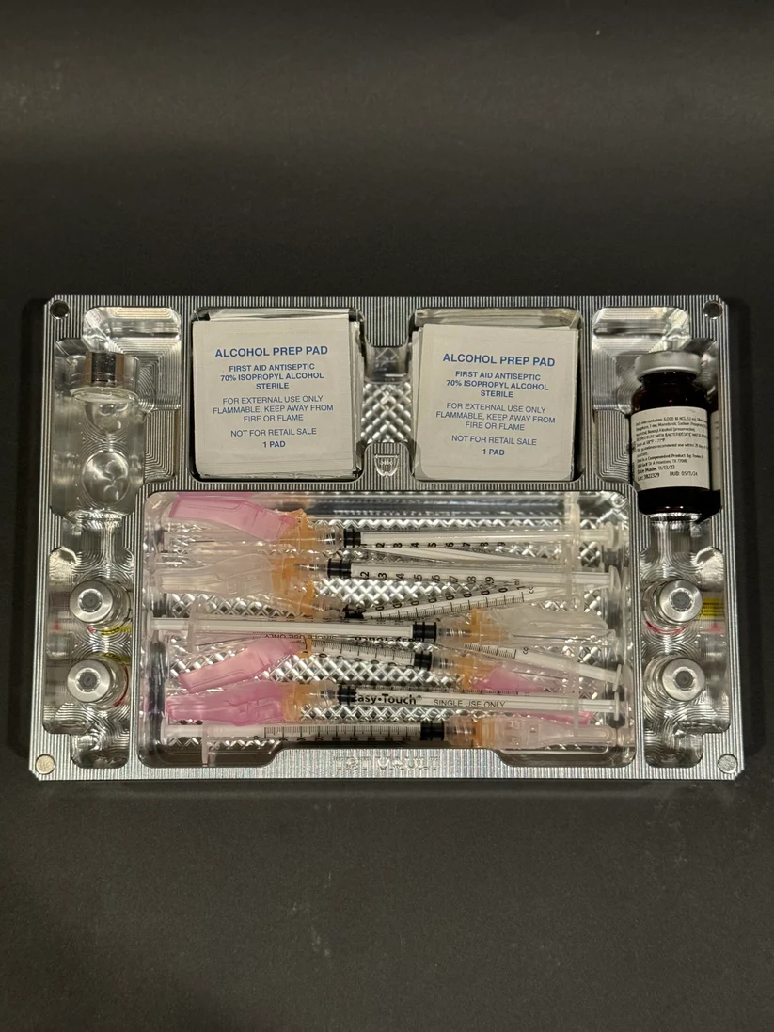
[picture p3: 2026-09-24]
reference/mega_top_reference.webp

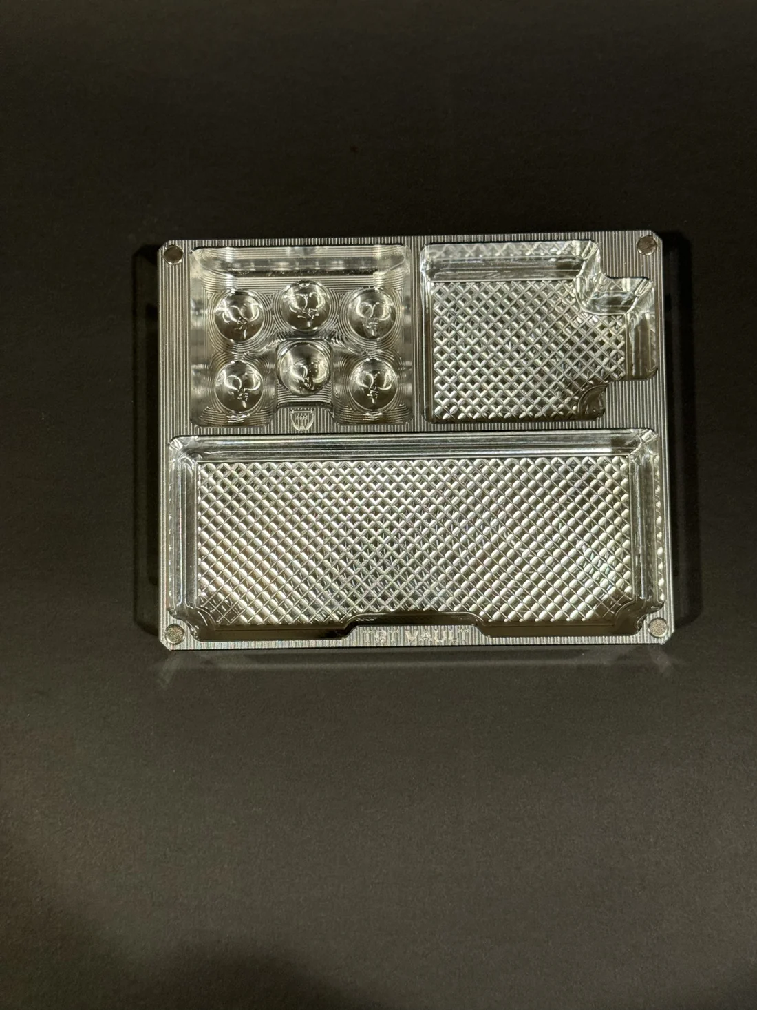
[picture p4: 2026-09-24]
reference/mini_top_reference.png

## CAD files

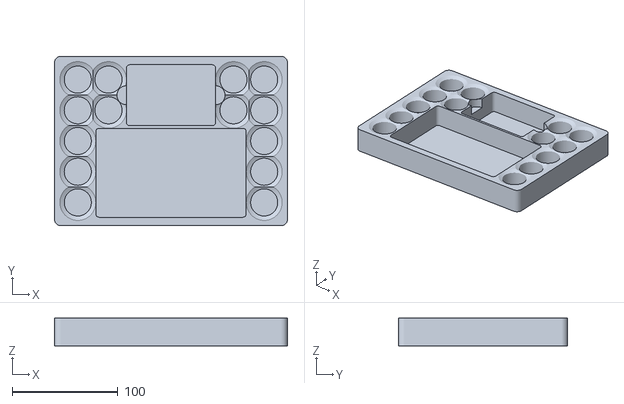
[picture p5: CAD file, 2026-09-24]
exports/stl/vault-lite-v0.1-cycle-tray-layout-study.stl
220.0 x 160.0 x 26.4

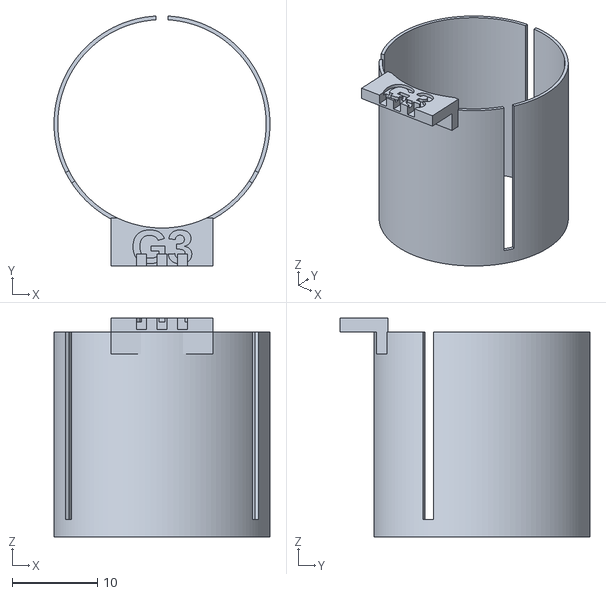
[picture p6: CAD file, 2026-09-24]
exports/stl/vault-lite-v0.3-vial-liner-g3.stl
25.3 x 29.3 x 25.6

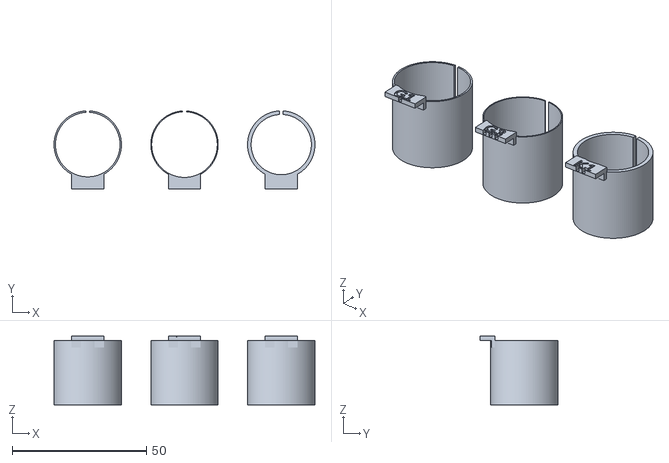
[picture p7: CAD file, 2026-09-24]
exports/stl/vault-lite-v0.2-vial-liners-g1-g3-k1.stl
97.1 x 29.1 x 25.6

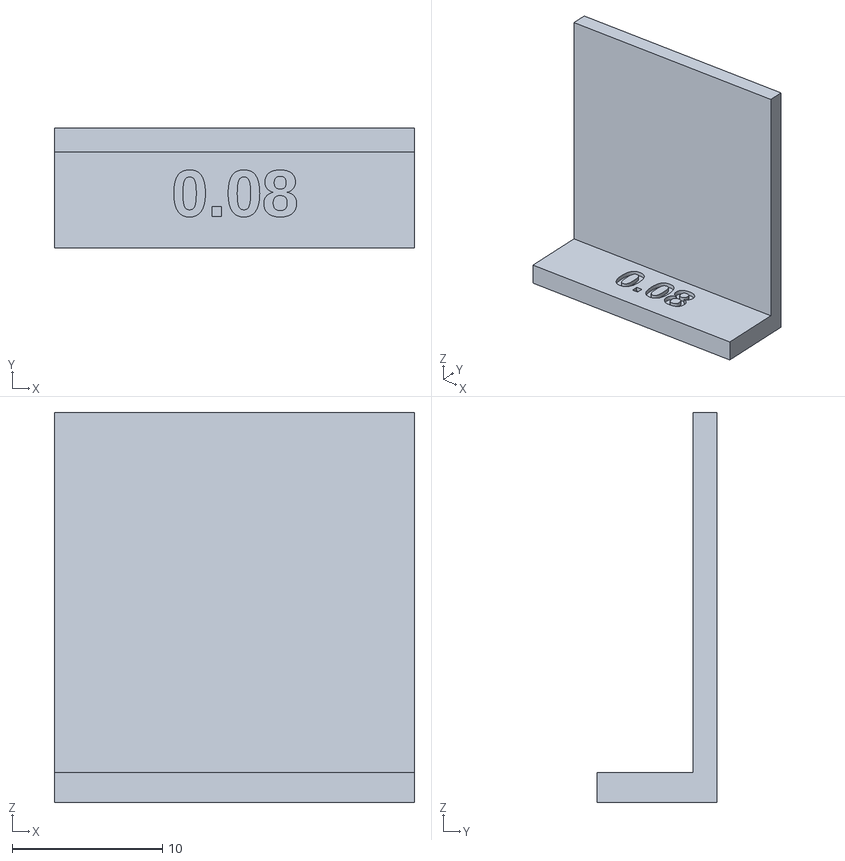
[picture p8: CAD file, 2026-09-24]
exports/stl/vault-lite-v0.1-fuzzy-008.stl
24.0 x 8.00 x 26.0

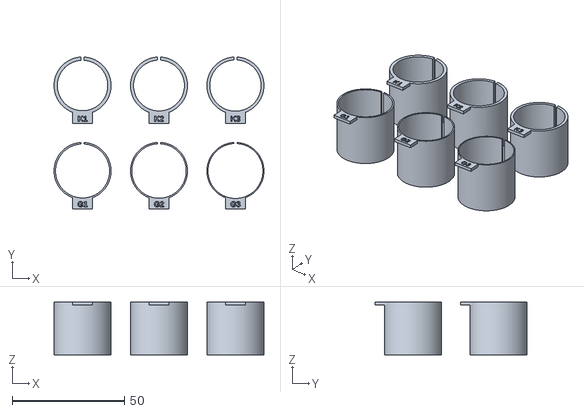
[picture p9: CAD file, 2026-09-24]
exports/stl/vault-lite-v0.1-vial-liner-iterations.stl
93.4 x 67.6 x 23.5

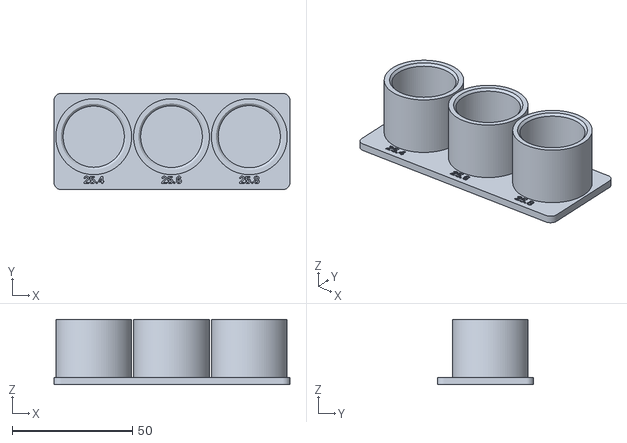
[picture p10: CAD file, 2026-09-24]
exports/stl/vault-lite-v0.1-vertical-vial-coupon.stl
98.0 x 40.0 x 27.0

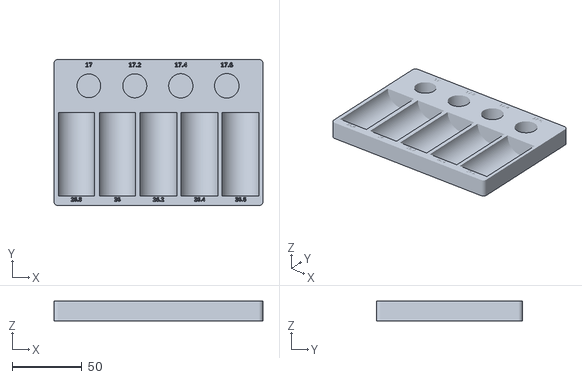
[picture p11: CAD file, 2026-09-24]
exports/stl/vault-lite-v0.1-vial-coupon.stl
150.0 x 105.0 x 14.0

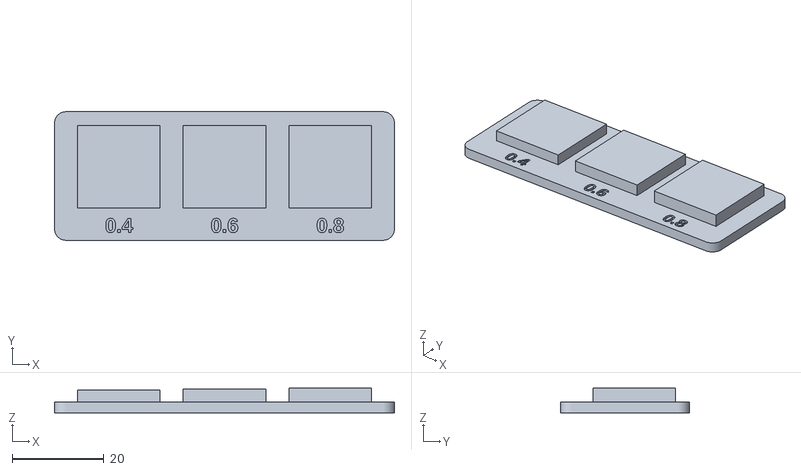
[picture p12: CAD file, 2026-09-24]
exports/stl/vault-lite-v0.1-magnet-cover-coupon.stl
74.0 x 28.0 x 5.40

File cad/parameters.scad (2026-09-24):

// Vault Lite shared parameters. Units are millimetres.
// Status tags: KNOWN, INFERRED, TESTED, or TBD.

// KNOWN — published exterior envelopes and compatibility limits.
micro_x = 152.40; // Reference ecosystem footprint: 6 x 3 in
micro_y = 76.20;
mini_x = 152.40;
mini_y = 127.00;
// KNOWN_REFERENCE — commercial Mega footprint retained for comparison only.
reference_mega_x = 215.90;
reference_mega_y = 152.40;

// SELECTED_DESIGN — original metric Vault Lite Large footprint shared by all
// Mega/Cycle/open-layer variants.
mega_x = 220.00;
mega_y = 160.00;
case_z = 44.45;
cycle_case_z = 63.50; // KNOWN_REFERENCE: written Cycle Mega product specification, 2.5 in

// Shared stack interface. These remain unresolved until physical testing.
stack_interface_version = "VL-SI-0";
stack_rebate_depth = undef;       // TBD_FROM_COUPON
stack_rebate_width = undef;       // TBD_FROM_COUPON
stack_xy_clearance = undef;       // TBD_FROM_COUPON
stack_corner_inset_x = undef;     // REQUIRED_AFTER_MAGNET_SELECTION
stack_corner_inset_y = undef;     // REQUIRED_AFTER_MAGNET_SELECTION

small_vial_max_d = 16.79;
small_vial_max_h = 38.48;
large_vial_max_d = 25.60;
large_vial_max_l = 56.00;

// KNOWN_USER_MEASURED — current physical supplies (cap included).
user_large_vial_max_l = 55.00;

// TESTED_CURRENT_VIAL — 17.00 mm coupon well comfortably fits user's 3 mL vial.
// This is 0.21 mm diametral clearance over the published 16.79 mm envelope.
small_vial_clearance = 0.21;
small_vial_cavity_d = small_vial_max_d + small_vial_clearance;

// TESTED_CURRENT_VIALS — 26.00 mm trough fits user's varied 5–10 mL vials.
// This is 0.40 mm diametral clearance over the published 25.60 mm envelope.
large_vial_clearance = 0.40;
large_vial_cavity_d = large_vial_max_d + large_vial_clearance;

// KNOWN_USER_MEASURED — round disc magnets, 6 mm diameter x 2 mm thick.
magnet_shape = "round";     // "round" or "rectangular"
magnet_d = 6.00;            // round magnets only
magnet_x = undef;           // rectangular magnets only
magnet_y = undef;           // rectangular magnets only
magnet_z = 2.00;
magnet_pocket_d = 6.20;     // PROVISIONAL; validate insertion fit in PETG
magnet_pocket_z = 2.20;     // PROVISIONAL; allows insertion below print plane
magnet_cover = 0.80;        // TESTED_VISUAL; best surface result, hold pending

// PROVISIONAL — printable defaults, to be validated in PETG.
outer_corner_radius = 6.0;
min_wall = 2.4;
floor_thickness = 2.4;
lid_thickness = 4.0;
lid_gap_xy = 0.30;
alignment_clearance = 0.25;

// PROVISIONAL lid visual language — multiples of a 0.20 mm layer height.
lid_emblem_raise = 0.60;
lid_bezel_raise = 0.80;      // bezel carries stacked load, 0.20 above emblem
lid_bezel_width = 2.40;
lid_bezel_edge_inset = 5.00;
lid_stack_relief_depth = 1.00; // underside clearance above bezel/emblem
lid_emblem_max_fraction = 0.42; // maximum fraction of smaller lid dimension

// Calibration ladders.
small_well_diameters = [17.0, 17.2, 17.4, 17.6];
large_trough_diameters = [25.8, 26.0, 26.2, 26.4, 26.6];
vertical_well_diameters = [25.4, 25.6, 25.8];
vertical_vial_cavity_d = 25.60; // TESTED_CURRENT_VIALS; selected Cycle Mega well
vertical_liner_outer_d = 25.40; // PROVISIONAL split collar; 0.20 mm diametral clearance
vertical_liner_clearance = vertical_vial_cavity_d - vertical_liner_outer_d;
gereropharm_liner_ids = [24.0, 24.2, 24.4];
kosa_liner_ids = [22.4, 22.6, 22.8];
magnet_cover_thicknesses = [0.4, 0.6, 0.8];

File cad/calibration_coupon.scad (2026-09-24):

include <parameters.scad>
use <primitives.scad>

/*
  Vault Lite V0.1 vial-fit coupon

  Print flat, text facing up, in the intended production material/profile.
  The wells and troughs are deliberately independent of unknown magnet sizes.
*/

$fn = 72;
coupon_x = 150;
coupon_y = 105;
coupon_z = 14;
coupon_radius = 3;
well_depth = 11;
trough_length = 60; // exceeds the KNOWN 56 mm maximum large-vial length

module coupon_blank() {
    rounded_box([coupon_x, coupon_y, coupon_z], coupon_radius);
}

module vial_fit_coupon() {
    difference() {
        coupon_blank();

        // Blind upright wells; 3 mm floor remains.
        for (i = [0 : len(small_well_diameters) - 1]) {
            x = 25 + i * 33;
            translate([x, 86, coupon_z - well_depth])
                cylinder(d = small_well_diameters[i], h = well_depth + 0.1);
        }

        // Full-length open semicircular troughs for horizontal large-vial fit.
        for (i = [0 : len(large_trough_diameters) - 1]) {
            x = 16 + i * 29.5;
            translate([x, 37, coupon_z])
                horizontal_trough(large_trough_diameters[i], trough_length);
        }

        // Recessed labels survive first-layer handling better than raised text.
        for (i = [0 : len(small_well_diameters) - 1]) {
            x = 25 + i * 33;
            translate([x, 101, coupon_z - 0.45])
                engraved_label(str(small_well_diameters[i]), 3.4, 0.5);
        }
        for (i = [0 : len(large_trough_diameters) - 1]) {
            x = 16 + i * 29.5;
            translate([x, 4.5, coupon_z - 0.45])
                engraved_label(str(large_trough_diameters[i]), 3.0, 0.5);
        }
    }
}

vial_fit_coupon();

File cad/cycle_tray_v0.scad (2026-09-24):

include <parameters.scad>
use <primitives.scad>

/*
  Cycle tray V0 layout study.

  The lower tray is one monolithic deck rather than separate vial rings and
  compartment frames. Wells, divots, and supply cavities are cut from that
  deck, eliminating narrow drop gaps and redundant inner/outer boundary walls.
  The final stack and bar-magnet interface remains intentionally deferred.
*/

$fn = 72;
layout_study = is_undef(LAYOUT_STUDY) ? true : LAYOUT_STUDY;

tray_x = mega_x;
tray_y = mega_y;
floor_z = 2.4;
wall = 2.4;
long_edge_magnet_rail = 8.0; // Top/bottom walls; exact pockets pending test.
feature_h = 24.0;
deck_top_z = floor_z + feature_h;
full_perimeter_h = cycle_case_z - lid_thickness;

well_id = vertical_vial_cavity_d;
divot_d = 34.0;
divot_r = divot_d / 2;
divot_sphere_r = 34.0;

outer_col_x = 22.0;
inner_col_x = 51.0;
row_ys = [22.0, 51.0, 80.0, 109.0, 138.0];

// Usable cavity openings. Each uses the exterior wall directly at Y-min or
// Y-max; the openings are separated by one 2.4 mm divider.
lower_opening = [39.0, long_edge_magnet_rail, 142.0, 84.0];
upper_opening = [68.0, 94.4, 84.0,
                 tray_y - long_edge_magnet_rail - 94.4];
opening_radius = 3.0;
finger_d = 18.0;

module cut_vials_and_divots() {
    sphere_center_z = deck_top_z
                    + sqrt(divot_sphere_r * divot_sphere_r
                           - divot_r * divot_r);

    for (side = [0, 1]) {
        outer_x = side == 0 ? outer_col_x : tray_x - outer_col_x;
        inner_x = side == 0 ? inner_col_x : tray_x - inner_col_x;

        for (y = row_ys) {
            translate([outer_x, y, floor_z - 0.1])
                cylinder(d = well_id, h = feature_h + 0.2);
            translate([outer_x, y, sphere_center_z])
                sphere(r = divot_sphere_r, $fn = 96);
        }

        for (i = [3, 4]) {
            translate([inner_x, row_ys[i], floor_z - 0.1])
                cylinder(d = well_id, h = feature_h + 0.2);
            translate([inner_x, row_ys[i], sphere_center_z])
                sphere(r = divot_sphere_r, $fn = 96);
        }
    }
}

module cut_opening(rect) {
    translate([rect[0], rect[1], floor_z])
        rounded_box([rect[2], rect[3], feature_h + 0.2], opening_radius);
}

module full_height_outer_rim() {
    if (!layout_study) {
        difference() {
            rounded_box([tray_x, tray_y, full_perimeter_h],
                        outer_corner_radius);
            translate([wall, wall, deck_top_z])
                rounded_box([tray_x - 2 * wall,
                             tray_y - 2 * wall,
                             full_perimeter_h - deck_top_z + 0.1],
                            outer_corner_radius - wall);
        }
    }
}

difference() {
    union() {
        // One closed deck: ordinary slicer infill supports the top skin without
        // accessible gaps between wells, bins, and the exterior wall.
        rounded_box([tray_x, tray_y, deck_top_z], outer_corner_radius);
        full_height_outer_rim();
    }

    cut_vials_and_divots();
    cut_opening(lower_opening);
    cut_opening(upper_opening);

    // Bilateral upper-half finger reliefs in the packet-bay side walls.
    for (x = [upper_opening[0], upper_opening[0] + upper_opening[2]]) {
        translate([x,
                   upper_opening[1] + upper_opening[3] / 2,
                   floor_z + feature_h * 0.55])
            cylinder(d = finger_d, h = feature_h * 0.55 + 0.2);
    }
}

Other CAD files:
exports/stl/vault-lite-v0.1-fuzzy-012.stl
exports/stl/vault-lite-v0.1-fuzzy-005.stl
cad/fuzzy_skin_coupon.scad
cad/magnet_coupon.scad
cad/primitives.scad
cad/vertical_vial_coupon.scad
cad/vial_liner_coupon.scad
cad/vial_liner_coupon_v2.scad
cad/vial_liner_g3_v3.scad

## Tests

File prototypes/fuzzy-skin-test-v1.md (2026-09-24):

# Fuzzy-skin coupon V1 results

Material: PETG.

Three minimal upright cards compared a fixed 0.40 mm point distance with fuzzy-skin thicknesses of 0.05, 0.08, and 0.12 mm.

## Result

- The 0.12 mm thickness produced the preferred fuzzy appearance.
- All fuzzy variants showed more surface artifacts than the normal smooth PETG finish.
- The texture did not provide enough cosmetic benefit to offset the additional artifacts.
- **Decision: use a normal smooth finish for production PETG parts.**

Smooth surfaces preserve the option to correct isolated rough areas after printing. Any sanding test should be performed on scrap first because sanding PETG can change gloss, haze the surface, soften edges, and alter functional dimensions. Do not sand stack registration, lid fits, magnet interfaces, vial wells, or bezel bearing surfaces unless correcting a specifically measured fit problem.

The fuzzy-skin CAD, STLs, and Bambu Studio instructions remain in the repository as calibration history. They are not the production profile.

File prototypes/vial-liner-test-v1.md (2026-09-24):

# Vial liner coupon V1 results

Material/profile: PETG, 0.20 mm profile.

## Physical results

- The small recessed G1–G3/K1–K3 labels were not reliably legible because of the PETG top-surface finish.
- The collar believed to be K1 fit the KOSA vial successfully. Because the printed identifier was difficult to read, treat the exact K1 selection as likely rather than fully confirmed.
- All three Gereropharm internal bores fit the Gereropharm vial when tested outside the 25.60 mm well.
- The Gereropharm vial was remeasured at 23.87 mm diameter, matching the original measurement.
- The Gereropharm collars required excessive force to enter the 25.60 mm well. This is an outer-fit failure, not a vial-bore failure.
- The 23.5 mm collar and rim-resting tab do not allow the collar body to bottom in the 24 mm-deep test well. Pressing on the tab to close the remaining gap risks breaking the tab.

## V2 requirements

- Preserve the tested Gereropharm bore ladder of 24.0, 24.2, and 24.4 mm until a preferred drag level is selected.
- Retain 22.4 mm as the leading KOSA bore, pending confirmation with a more legible identifier.
- Reduce the common outer diameter from 25.40 mm. Start V2 at **25.10 mm**, giving 0.50 mm nominal diametral clearance in the 25.60 mm well.
- Extend the collar body to the full **24.0 mm well depth**.
- Place the extraction feature entirely above the well rim so the collar body, not the tab, carries downward force.
- Replace small text as the primary identifier with large physical coding such as one, two, or three edge notches. Text may remain secondary.
- Verify that the full-depth liner remains removable and does not lift out with the vial.

The V1 printable source and STL remain unchanged as a record of the tested artifact. Implement these changes in a separately identified V2 coupon.

V2 scope was subsequently reduced to **G1, G3, and K1 only**. G2 and the wider KOSA variants are intentionally omitted to save print time and material.

## V2 in-process observations

- G3 did not receive cylindrical-wall toolpaths with the 0.4 mm nozzle profile. Its 25.10 mm OD and 24.40 mm ID leave only a 0.35 mm radial wall; Bambu Studio retained the thicker label/ear but omitted the collar wall.
- G1 can be forced into the 25.60 mm well around the Gereropharm vial, but after removing the vial it cannot be reinserted normally. The 24.00 mm ID provides only 0.13 mm nominal diametral vial clearance and is rejected for usability when constrained by the well.
- Do not use a 0.2 mm nozzle merely to preserve the G3 geometry. The production liner should remain printable with the standard 0.4 mm nozzle.

Next Gereropharm pass: print one G3-derived liner with a 24.40 mm ID and an approximately 25.24–25.30 mm printable OD, using exterior reliefs/flats to reduce contact area. Verify slicer toolpaths before printing. G2 is still unnecessary unless G3 proves excessively loose.

Implemented as V3 with a 25.30 mm OD, 0.45 mm radial wall, primary split, and two near-full-height relief slots that form three flexible petals above a 2 mm connecting band. The standalone mesh validates, but continuous wall toolpaths must be confirmed in Bambu Studio before printing.

## Final Gereropharm decision

The Gereropharm vial is accepted directly in the standard 25.60 mm well without a liner. Its measured 23.87 mm body leaves 1.73 mm diametral clearance (approximately 0.865 mm per side), which is adequate in actual use. Further Gereropharm liner development is closed because the added slicing, insertion, and handling complexity does not provide enough practical benefit.

The G1/G3 and standalone G3 files remain in the repository as test history only. K1 remains the sole active removable-liner candidate for the narrower KOSA vial.

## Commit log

2026-09-24 Initial Vault Lite parametric storage project
    [calibration_coupon.scad, magnet_coupon.scad, parameters.scad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]
2026-09-24 Add Cycle Mega vertical vial fit coupon
    [parameters.scad, vault-lite-v0.1-vertical-vial-coupon.stl, vertical_vial_coupon.scad]
2026-09-24 Narrow Cycle Mega vial well coupon range
    [parameters.scad, vault-lite-v0.1-vertical-vial-coupon.stl, vertical_vial_coupon.scad]
2026-09-24 Select Cycle Mega well and plan reducer liners
    [parameters.scad]
2026-09-24 Add removable vial liner iterations
    [parameters.scad, vault-lite-v0.1-vial-liner-iterations.stl, vial_liner_coupon.scad]
2026-09-24 Record packaged syringe and needle lengths
2026-09-24 Add minimal fuzzy skin comparison coupons
    [fuzzy_skin_coupon.scad, vault-lite-v0.1-fuzzy-005.stl, vault-lite-v0.1-fuzzy-008.stl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]
2026-09-24 Add reduced full-depth vial liner V2 pass
    [vault-lite-v0.2-vial-liners-g1-g3-k1.stl, vial_liner_coupon_v2.scad]
2026-09-24 Add printable-wall G3 liner revision
    [vault-lite-v0.3-vial-liner-g3.stl, vial_liner_g3_v3.scad]
2026-09-24 Add Cycle tray V0 layout study
    [cycle_tray_v0.scad, vault-lite-v0.1-cycle-tray-layout-study.stl]
2026-09-24 Add machined divots to Cycle vial banks
    [cycle_tray_v0.scad, vault-lite-v0.1-cycle-tray-layout-study.stl]
2026-09-24 Unify Cycle tray deck and exterior walls
    [cycle_tray_v0.scad, vault-lite-v0.1-cycle-tray-layout-study.stl]
2026-09-24 Adopt 220 by 160 Vault Lite Large footprint
    [cycle_tray_v0.scad, parameters.scad, vault-lite-v0.1-cycle-tray-layout-study.stl]
2026-09-24 Reserve long-edge walls for bar magnets
    [cycle_tray_v0.scad, vault-lite-v0.1-cycle-tray-layout-study.stl]
